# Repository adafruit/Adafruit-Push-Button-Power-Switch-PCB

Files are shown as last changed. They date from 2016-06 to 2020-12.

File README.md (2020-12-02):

## Adafruit Push Button Power Switch PCB
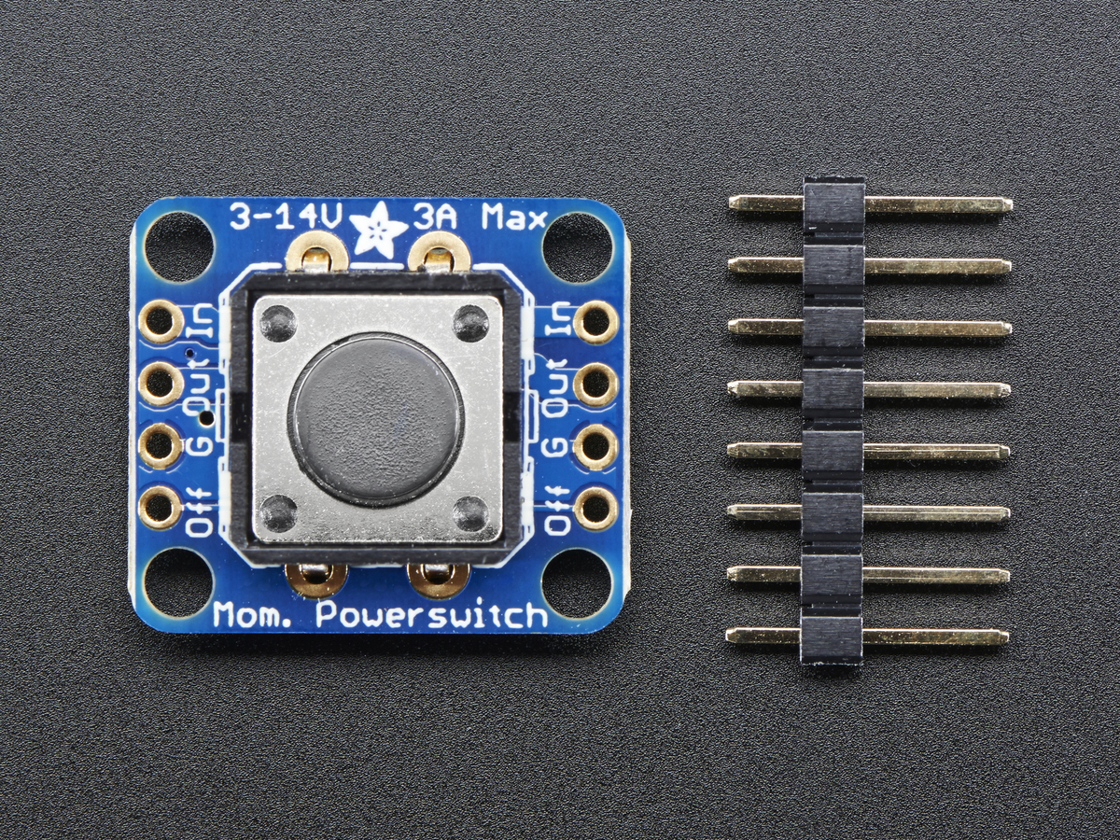
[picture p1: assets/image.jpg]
<a href="http://www.adafruit.com/products/1400"><br/>
Click here to purchase one from the Adafruit shop</a>

The Adafruit Push-button Power Switch is a tidy little design that lets you control a DC power source using an everyday tactile button. The breakout uses a latching analog circuit that is triggered by a push of the button. Press once to turn on, then press again to turn off. The circuit uses a 3A P-FET to connect and disconnect the IN pin to the OUT pin. Works great from 3V to 14VDC and up to 3A (although the FET gets a little toasty at continuous 3A draw) yet has only 0.5uA quiescent current draw.

Using it is easy: connect the power source to Ground and IN, then the load from Ground to OUT. We include a 12mm tactile switch that works well but you can solder in your own switch as well. Press the button (or short the button pins) to alternate between on or off. A on-board red LED will light up when active so you know its working. There's a fourth KILL pin, which you can use to turn off the load and/or keep it off even if the button is pressed. When 1 or more volts is applied it will instantly turn off the FET. This allows your project to turn itself off.

Comes with a assembled & tested bread-board friendly breakout board with four mounting holes, a 12mm tactile button, and some 0.1" male header you can solder to the board to plug it into a breadboard.

PCB files for the Push Button Power Switch PCB. The format is EagleCAD schematic and board layout
- https://www.adafruit.com/products/1400

### License

Adafruit invests time and resources providing this open source design, please support Adafruit and open-source hardware by purchasing products from [Adafruit](https://www.adafruit.com)!

All text above must be included in any redistribution

Designed by Limor Fried/Ladyada for Adafruit Industries.
Creative Commons Attribution/Share-Alike, all text above must be included in any redistribution. 
See license.txt for additional information.

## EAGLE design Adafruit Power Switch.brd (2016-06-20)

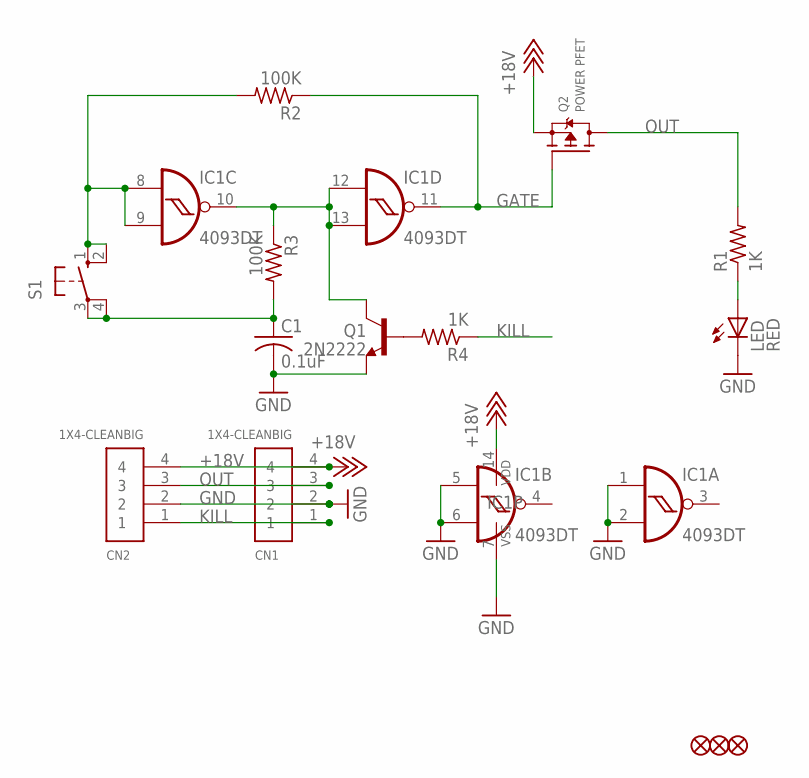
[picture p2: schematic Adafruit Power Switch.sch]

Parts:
C1: 0.1uF; C0805
CN1, CN2: 1X4-CLEANBIG; 1X04-CLEANBIG
FID1, FID2, FID3: FIDUCIAL""; FIDUCIAL_1MM
IC1: 4093DT; MC14093B-TSSOP14
LED: RED; CHIP-LED0805
Q1: 2N2222; SOT23-BEC
Q2: POWER PFET; SOT23-WIDE
R1, R4: 1K; R0805
R2, R3: 100K; R0805
S1: 40-XX-ROUND; B3F-40XX-ROUND

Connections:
+18V: CN1.4, CN2.4, IC1.14 (VDD), Q2.2 (S)
GATE: IC1.11 (O), Q2.1 (G), R2.1
GND: C1.2, CN1.2, CN2.2, IC1.1 (I0), IC1.2 (I1), IC1.5 (I0), IC1.6 (I1), IC1.7 (VSS), LED.C, Q1.E
KILL: CN1.1, CN2.1, R4.1
unnamed: Q1.B, R4.2
unnamed: IC1.10 (O), IC1.12 (I0), IC1.13 (I1), Q1.C, R3.1
unnamed: LED.A, R1.1
unnamed: C1.1, R3.2, S1.3, S1.4 (P1)
unnamed: IC1.8 (I0), IC1.9 (I1), R2.2, S1.1 (S), S1.2 (S1)
OUT: CN1.3, CN2.3, Q2.3 (D), R1.2

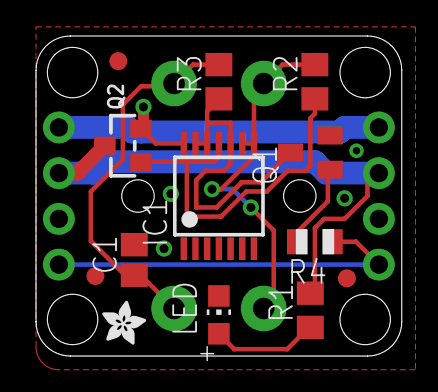
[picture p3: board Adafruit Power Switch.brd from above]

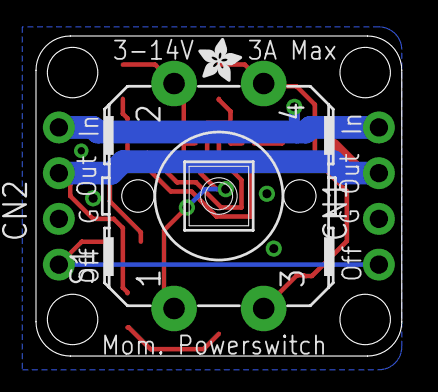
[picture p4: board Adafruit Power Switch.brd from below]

Board: 2 copper layers, 20.3 x 17.8 mm, 17 parts (4 on the bottom side), 10 nets.

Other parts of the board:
U$1, U$2: ADAFRUIT_2.5MM

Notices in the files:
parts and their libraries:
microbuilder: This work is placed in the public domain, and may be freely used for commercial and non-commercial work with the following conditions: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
